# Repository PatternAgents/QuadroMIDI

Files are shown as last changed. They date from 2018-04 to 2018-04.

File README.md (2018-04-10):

# QuadroMIDI - Four channel MIDI Trigger I/O



Format : ERA / Eurorack / Breadboard Friendly

Height : 1U 

Width: 16HP

Depth : 1.0 cm

Power : +12V 40mA, -12V 40mA

Jacks : Thonkiconn Jacks (PJ301M-12)

The QuadroMIDI is a low cost, embeddable MIDI Trigger module

* Embedded Rack Architecture (Eurorack compatible)
* Optically Isolated MIDI Input Jack
* Driven MIDI Output Jack
* MIDI Clock Output Jack
* MIDI Run/Stop Output Jack
* Four (4) DC coupled  Trigger input channels
* Four (4) DC coupled  Trigger output channels
* Add an optional Front-Panel board for mounting in ERA and/or Eurorack enclosures

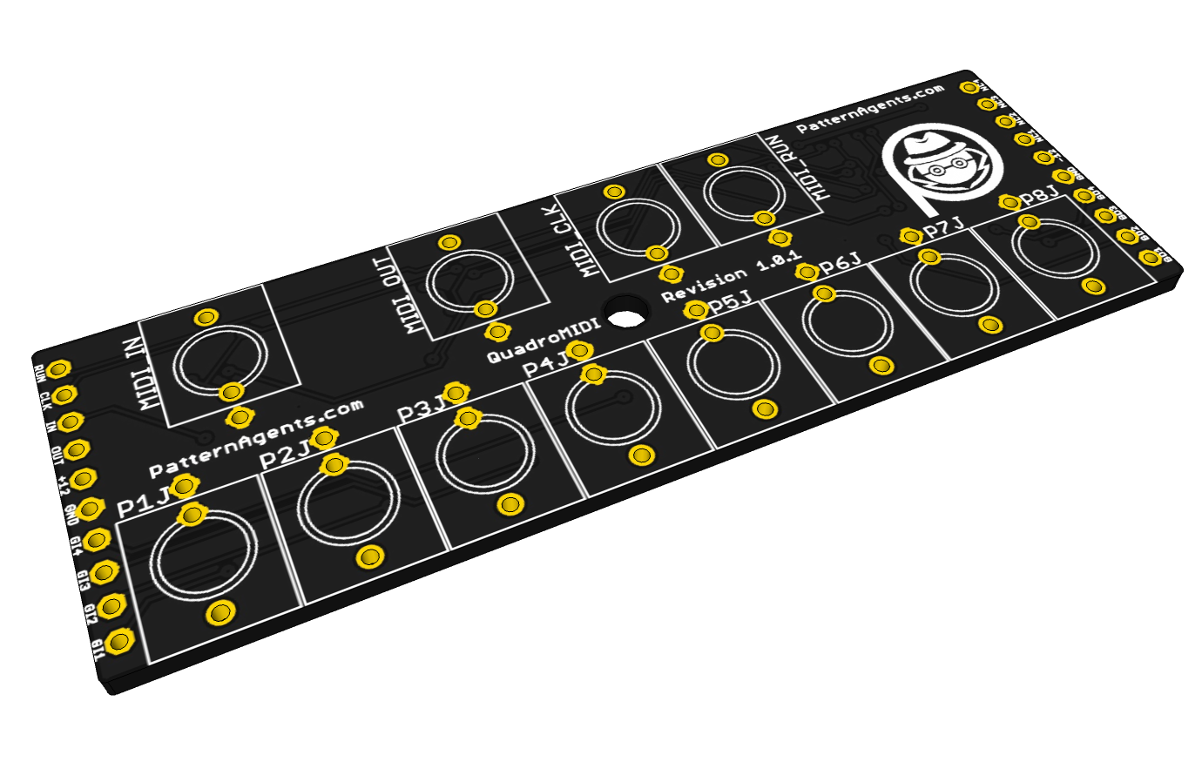
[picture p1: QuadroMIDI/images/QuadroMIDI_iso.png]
patternagents QuadroMIDI
[QuadroMIDI](https://github.com/patternagents/QuadroMIDI)

**thingSoC ERA** are OEM friendly implementations that implement various reference 
circuits for demonstrating the use of the PatternAgents IP and Libraries.

---------------------------------------
## QuadroMIDI Applications <a name="QuadroMIDI_Applications"/>

* MIDI to Trigger (Drum Piezo or other Human Interface)
* Add-on board for QuadroTeenia (MIDI I/O and Trigger I/O)

---------------------------------------
## QuadroMIDI Status <a name="QuadroMIDI_Status"/>

**4/10/2018:** 
Revision 1.0.0 - Initial Layout sent from OSHpark

---------------------------------------
## QuadroMIDI Model Images

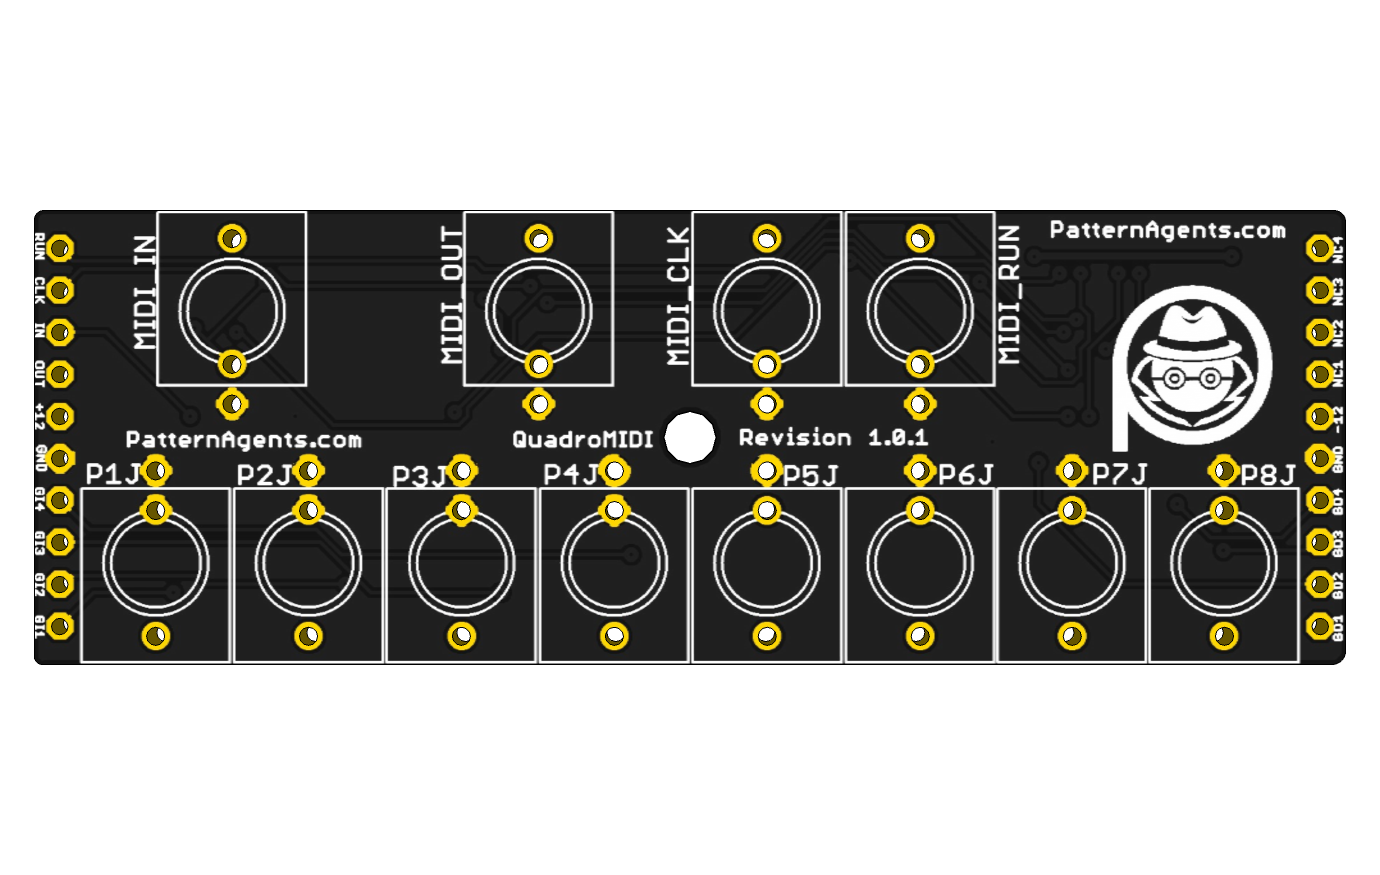
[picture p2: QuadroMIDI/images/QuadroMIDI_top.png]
patternagents QuadroMIDI
[QuadroMIDI](https://github.com/patternagents/QuadroMIDI)

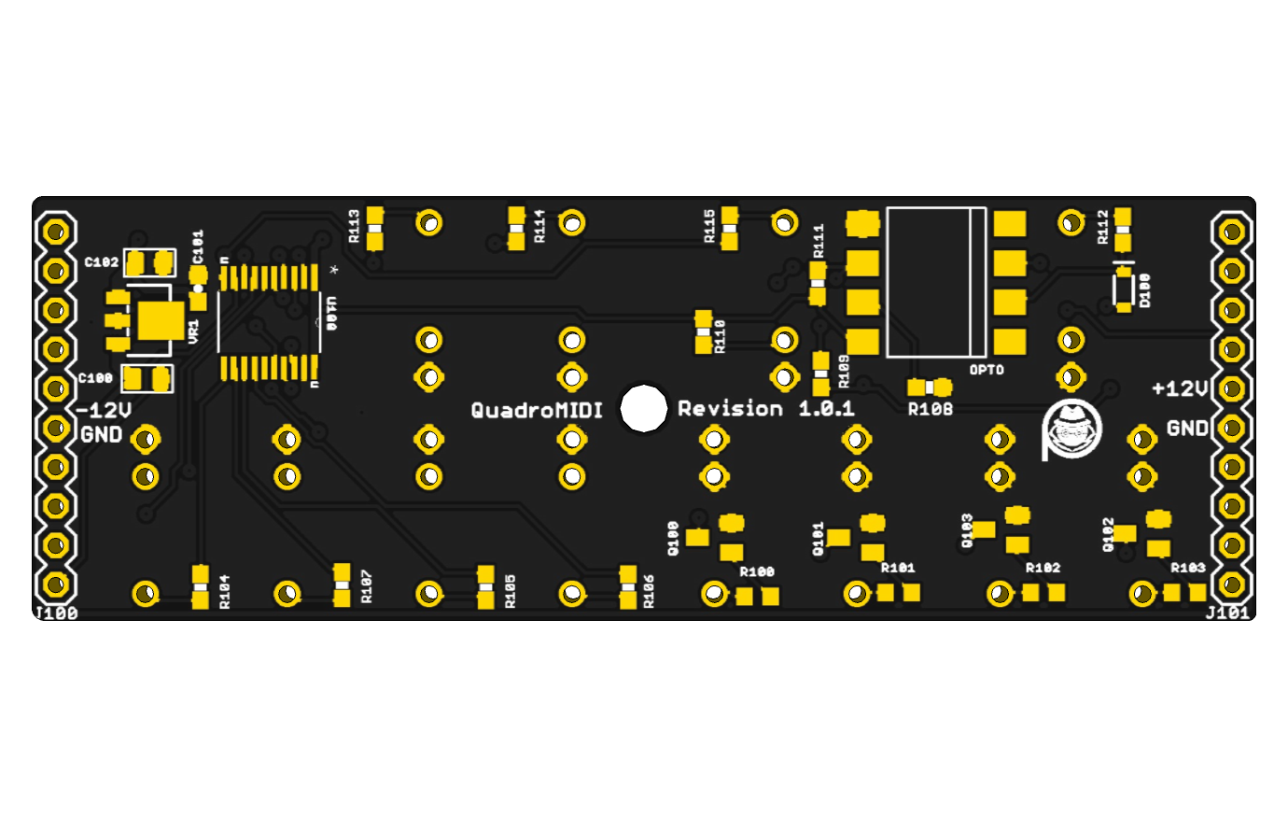
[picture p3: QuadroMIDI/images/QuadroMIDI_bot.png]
patternagents QuadroMIDI
[QuadroMIDI](https://github.com/patternagents/QuadroMIDI)

---------------------------------------

## QuadroMIDI Documentation Index <a name="QuadroMIDI_documentation_index"/>

[QuadroMIDI Project](http://thingsoc.github.io/projects/QuadroMIDI.html)

[QuadroMIDI Hardware](https://github.com/patternagents/QuadroMIDI/tree/master/QuadroMIDI/revisions/R1_0_0)

---------------------------------------

## Documentation Index <a name="documentation_index"/>

[Organization Website](http://patternagents.github.io)

[FAQ - Frequently Asked Questions](http://thingsoc.github.io/support/faq.html)

---------------------------------------

[thingSoC 
*PatternAgents, LLC*](http://thingsoc.github.io)

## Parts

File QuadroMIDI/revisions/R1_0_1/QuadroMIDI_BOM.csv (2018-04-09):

Qty | Value | Device | Package | Parts | Description
7 |  | RESISTOR0603-RES | 0603-RES | R104, R105, R106, R107, R113, R114, R115 | Resistor
1 | 0.1uF | CAP0603-CAP | 0603-CAP | C101 | Capacitor
1 | 0.5A/40V/420mV | DIODE-SCHOTTKY-PMEG4005EJ | SOD-323 | D100 | Schottky diode
4 | 100k | R-US_R0603 | R0603 | R100, R101, R102, R103 | RESISTOR, American symbol
3 | 1K | RESISTOR0603 | 0603-RES | R108, R109, R111 | Resistor
2 | 220 | RESISTOR0603 | 0603-RES | R110, R112 | Resistor
2 | 4.7uf | CERAMIC-4.7UF-25V-10%-X5R(0805) | C0805 | C100, C102 | 302010146
1 | 6N137SMT | 6N137SMT | DIL8-SMD | OPTO | MOTOROLA OPTO COUPLER
1 | 78L05 | 78LXX-SOT89 | SOT89 | VR1 | VOLTAGE REGULATOR
2 | F10 | M10SILK_FEMALE_PTH | 1X10_OCTO | J100, J101 | Header 10
10 | JACK-3_5MM-MONO-SW-MIN | JACK-3_5MM-MONO-SW-MIN | WQP_PJ301M-MIN | MIDI_CLK, MIDI_RUN, P1J, P2J, P3J, P4J, P5J, P6J, P7J, P8J | Jack, 3.5mm, RIght Angle, Though-Hole
2 | JACK-3_5MM-STEREO | JACK-3_5MM-STEREO | WQP_PJ301M-MIN | MIDI_IN, MIDI_OUT | Stereo 3.5mm Jack (TRS - Tip, Ring, Sleeve)
4 | MMBT3904 | MMBT3904LT1-NPN-SOT23-BEC | SOT23-BEC | Q100, Q101, Q102, Q103 | NPN Transistror
1 | PA_LOGO_SYMLARGE | PA_LOGO_SYMLARGE | PA_LOGO_AGENT_LRG_SYM | $$U$1 | PatternAgents Logo Symbol
1 | PA_LOGO_SYMSMALL | PA_LOGO_SYMSMALL | PA_LOGO_AGENT_SMALL_SYM | U$100 | PatternAgents Logo Symbol
1 | SN74HC245PW | SN74HC245PW | SOP65P640X120-20N | U100 | OCTAL BUS TRANSCEIVERS

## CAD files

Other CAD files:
QuadroMIDI/revisions/R1_0_1/eagleUp/QuadroMIDI.skp

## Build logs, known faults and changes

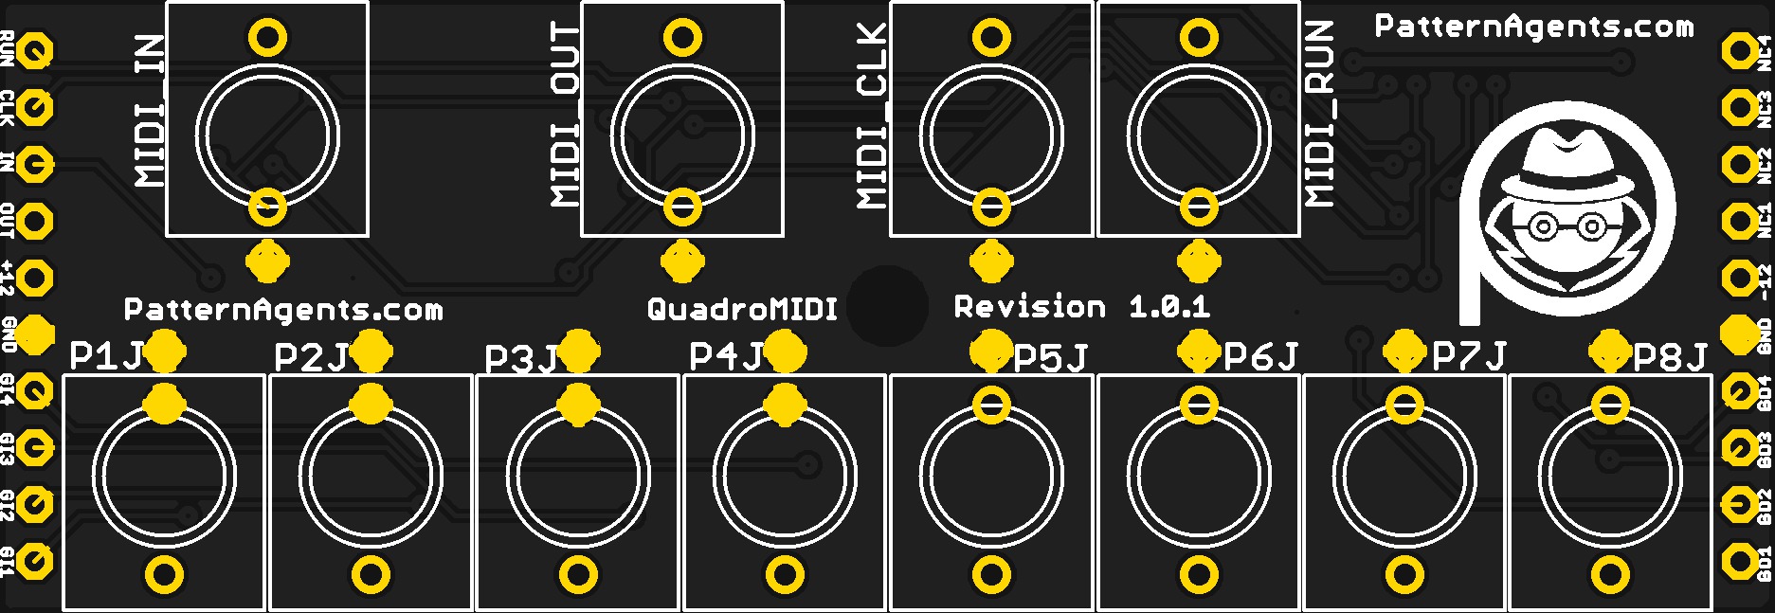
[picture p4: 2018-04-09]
QuadroMIDI/revisions/R1_0_1/eagleUp/eagleUp_QuadroMIDI_board_top.jpg

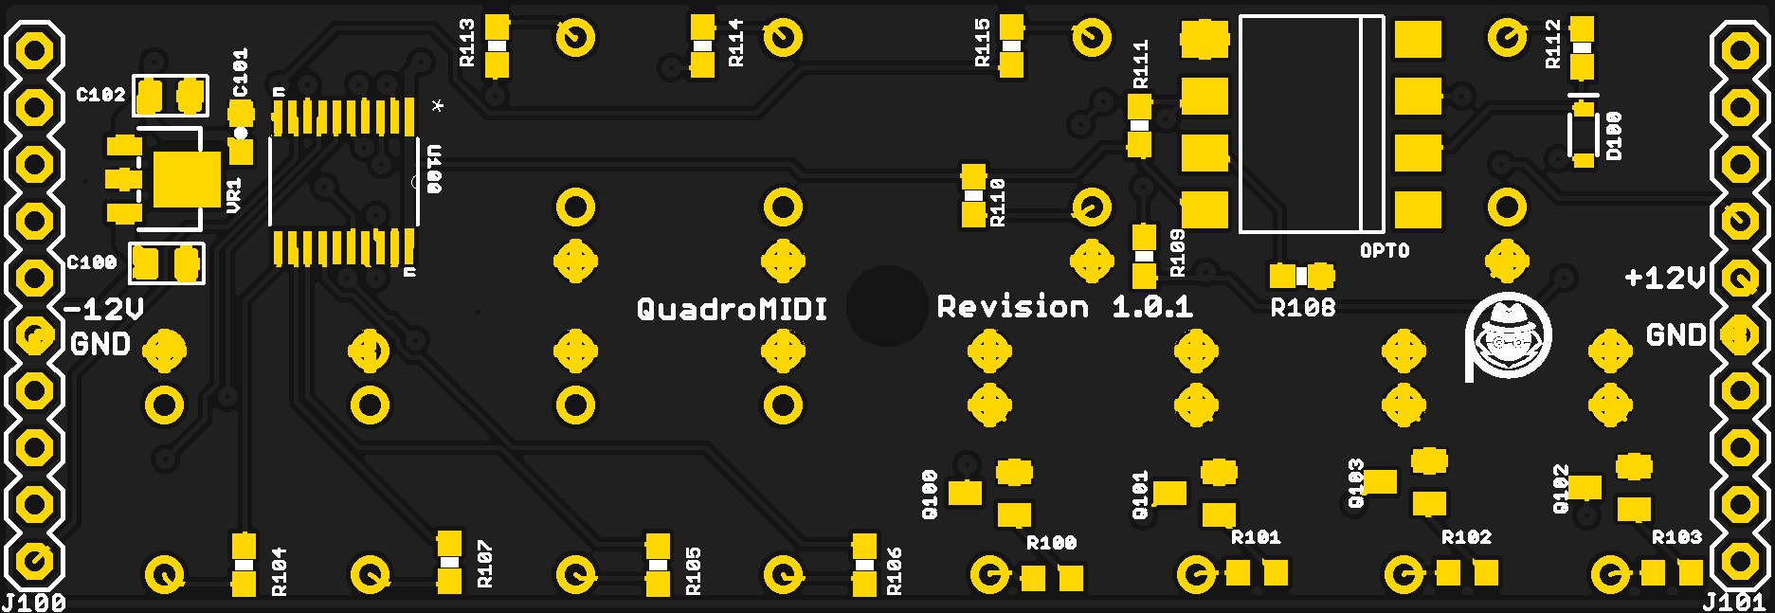
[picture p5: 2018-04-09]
QuadroMIDI/revisions/R1_0_1/eagleUp/eagleUp_QuadroMIDI_board_bottom.jpg

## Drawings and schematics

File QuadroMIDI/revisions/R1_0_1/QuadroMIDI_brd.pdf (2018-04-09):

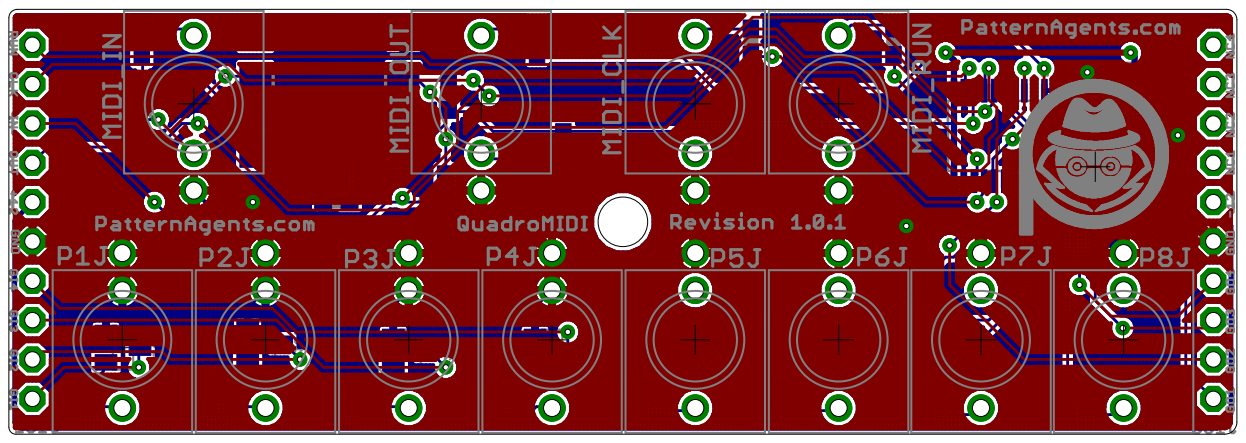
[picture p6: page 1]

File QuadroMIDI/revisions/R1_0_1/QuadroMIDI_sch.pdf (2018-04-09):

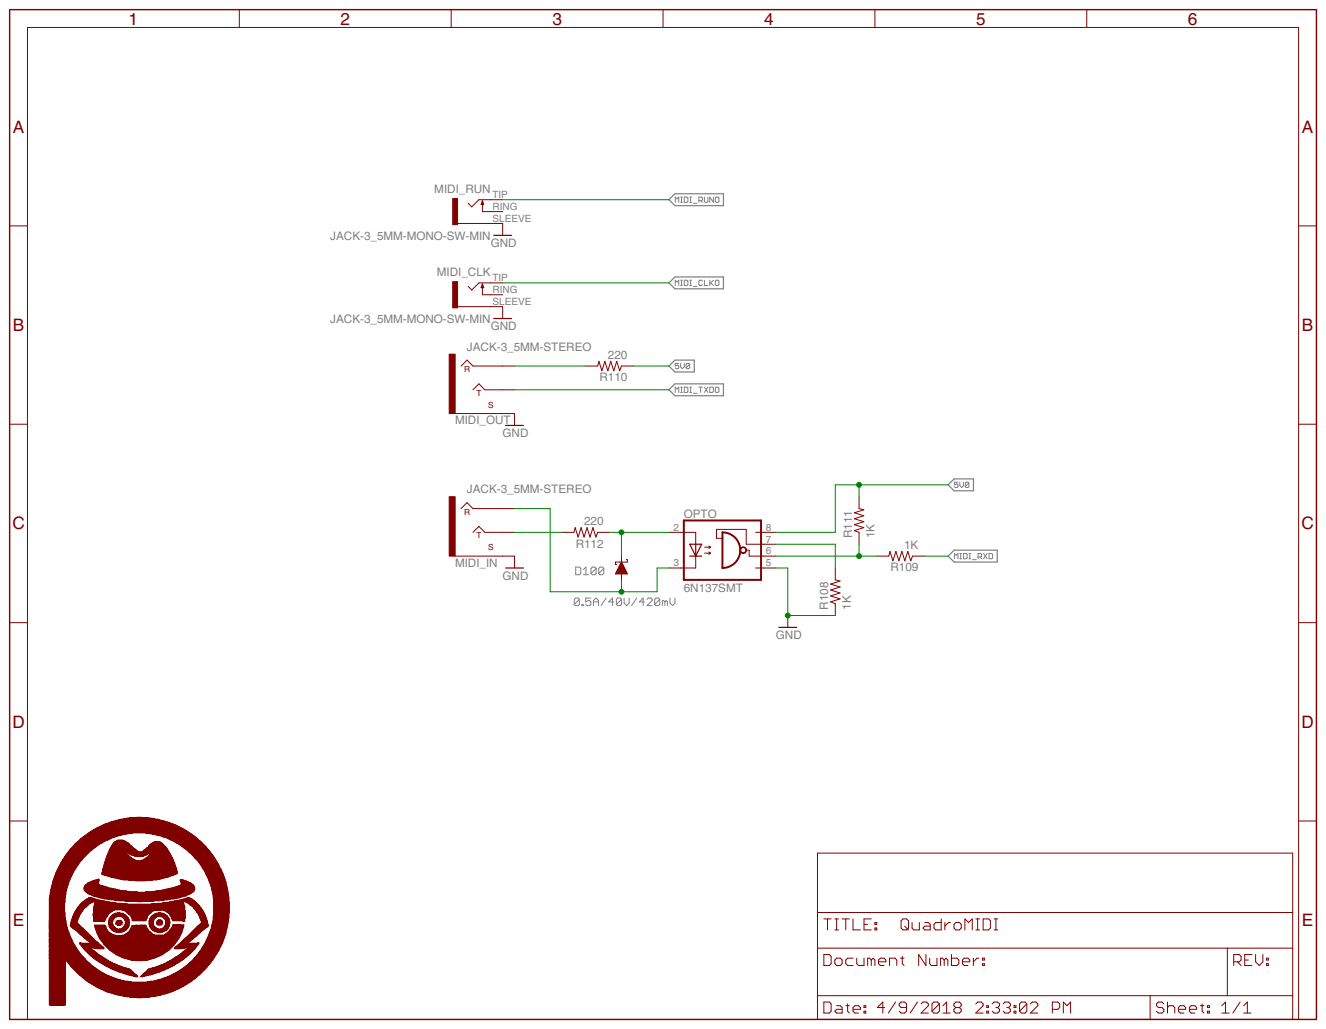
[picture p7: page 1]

JACK-3_5MM-MONO-SW-MIN

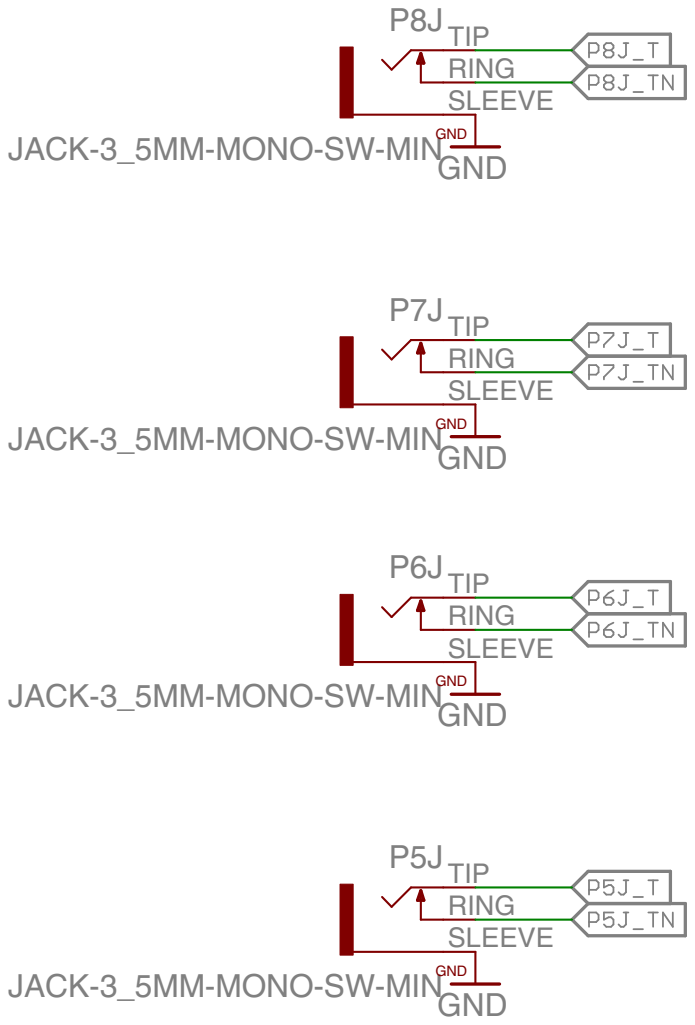
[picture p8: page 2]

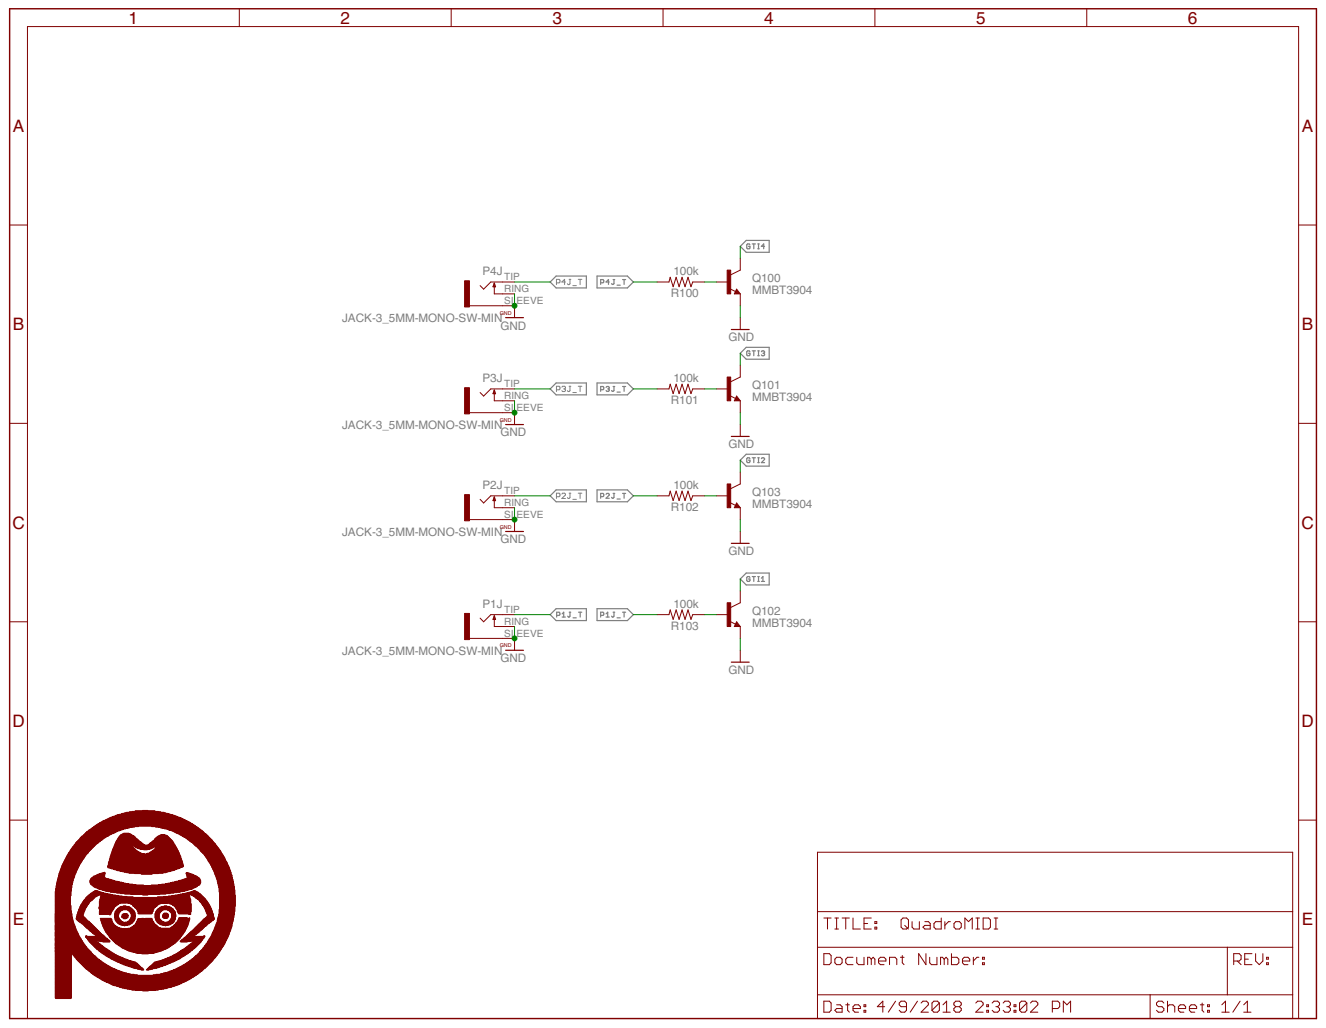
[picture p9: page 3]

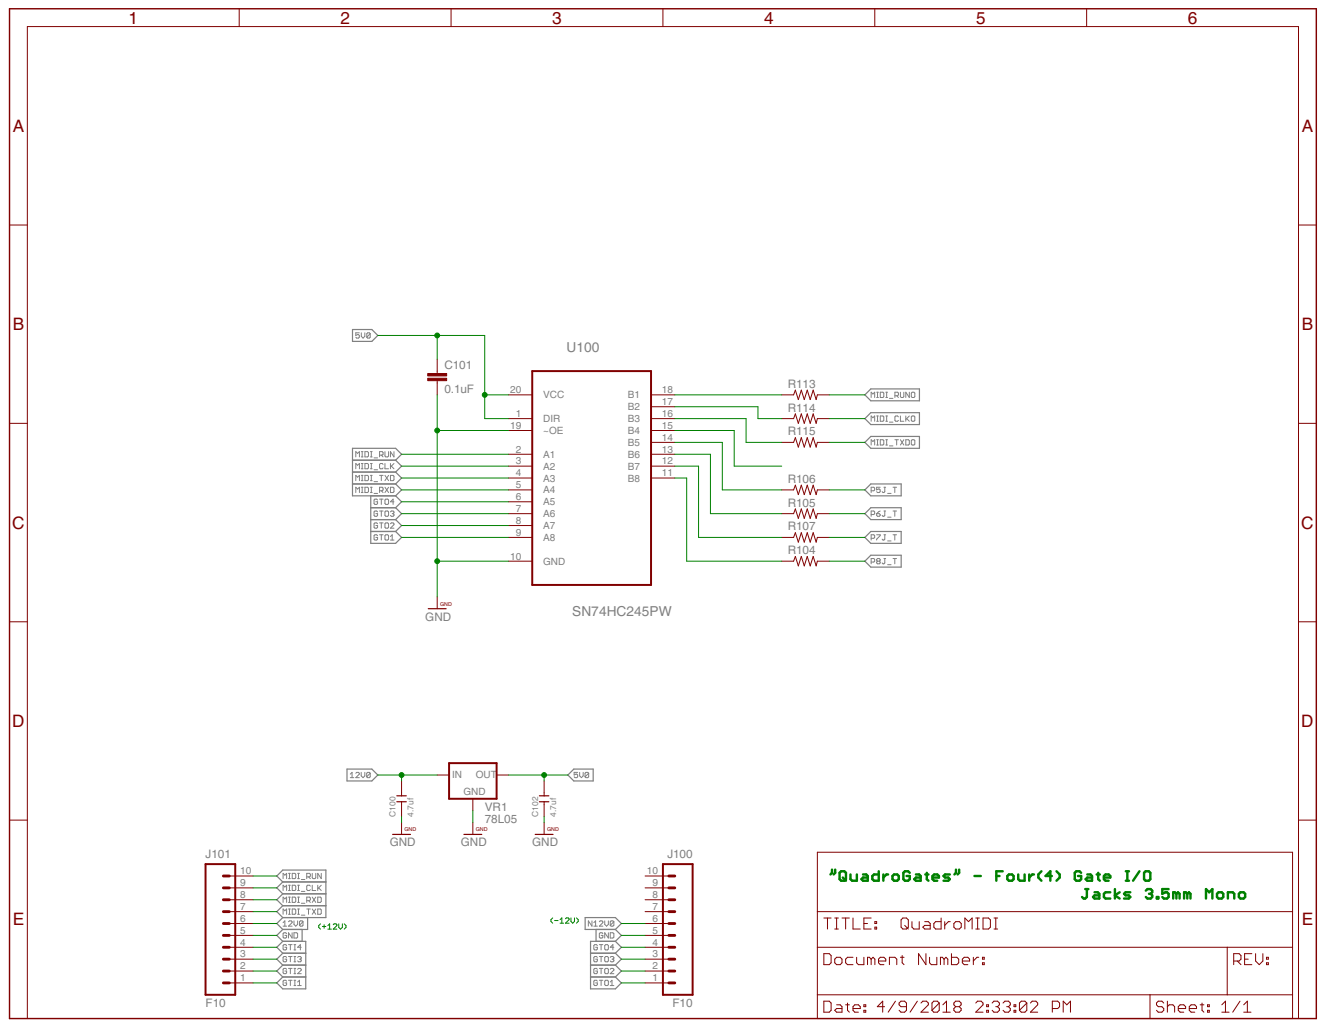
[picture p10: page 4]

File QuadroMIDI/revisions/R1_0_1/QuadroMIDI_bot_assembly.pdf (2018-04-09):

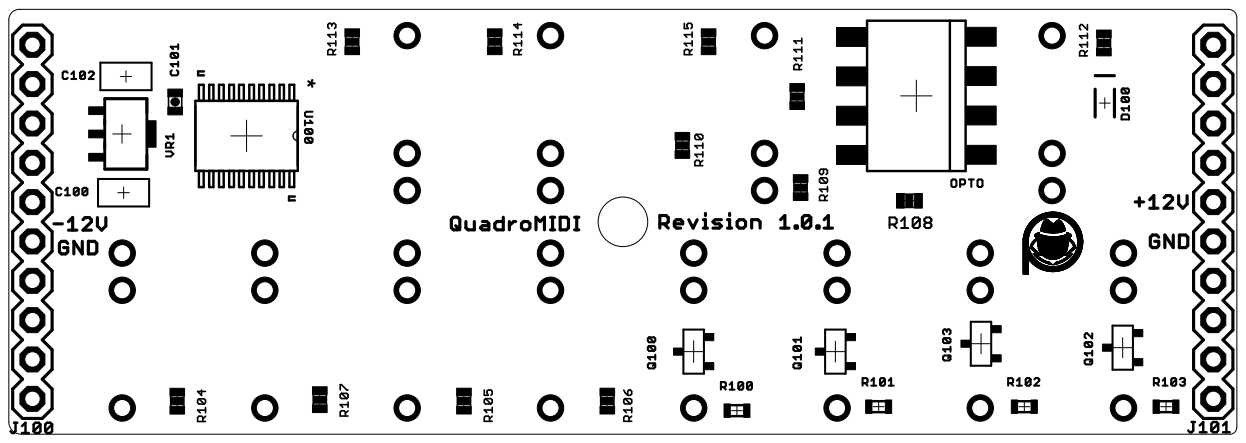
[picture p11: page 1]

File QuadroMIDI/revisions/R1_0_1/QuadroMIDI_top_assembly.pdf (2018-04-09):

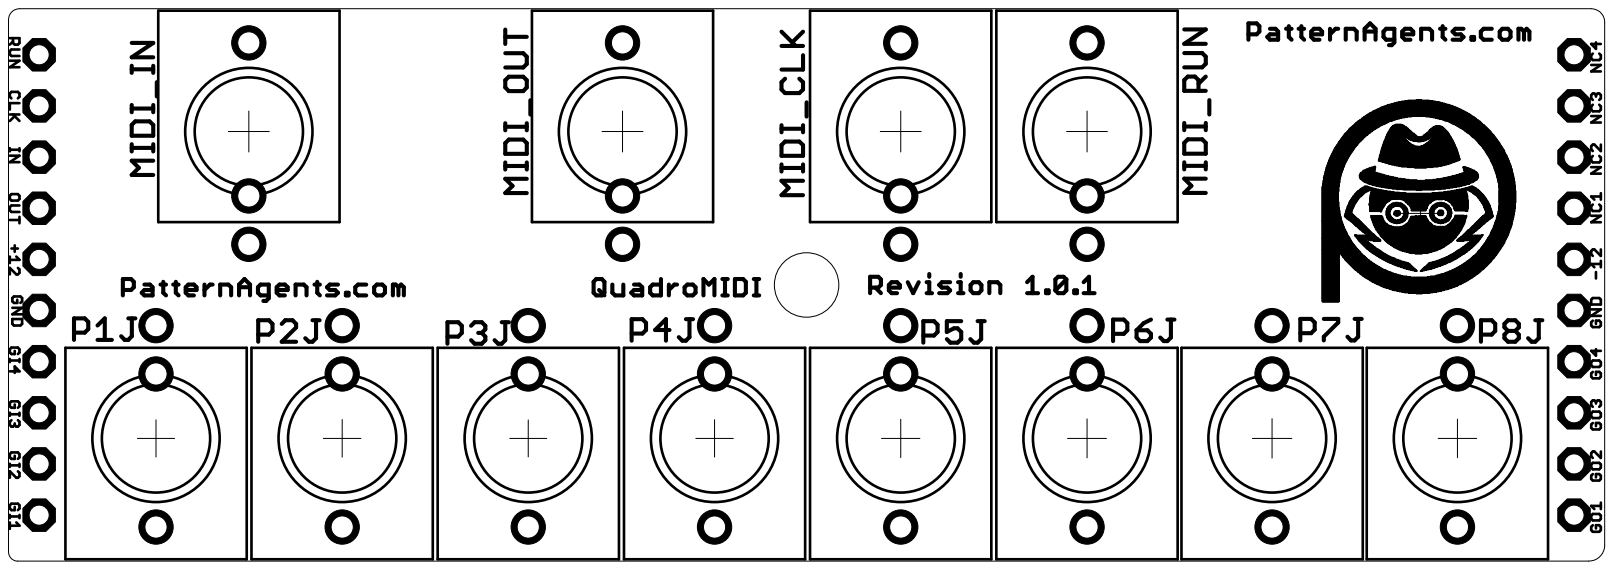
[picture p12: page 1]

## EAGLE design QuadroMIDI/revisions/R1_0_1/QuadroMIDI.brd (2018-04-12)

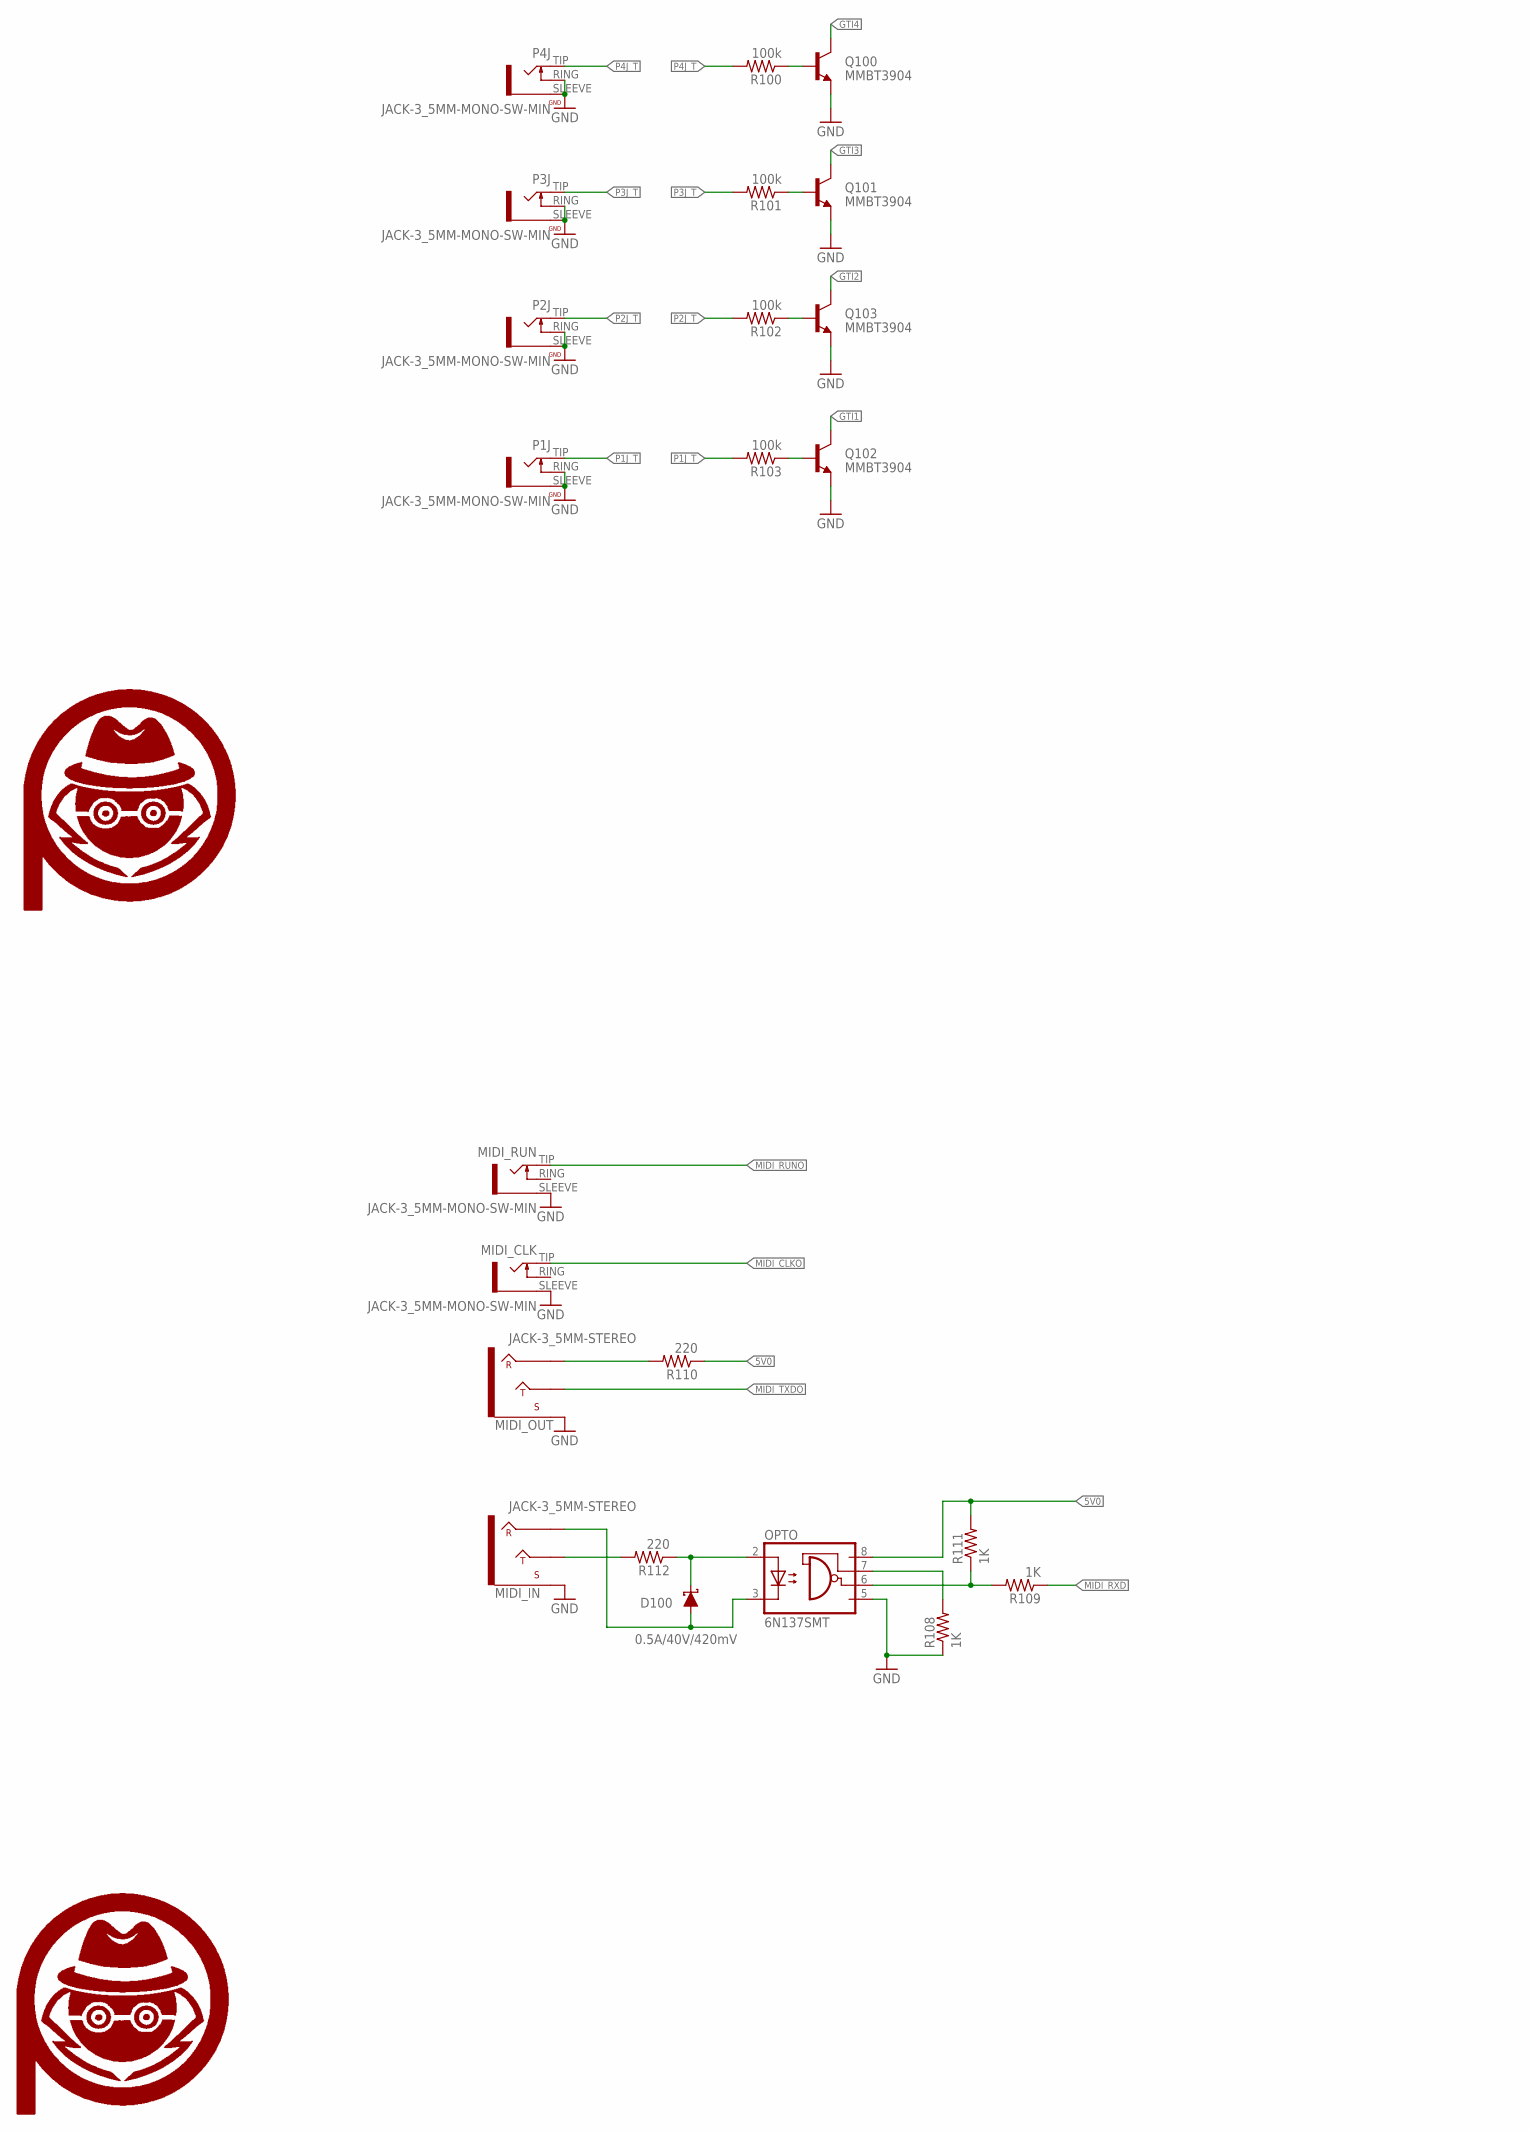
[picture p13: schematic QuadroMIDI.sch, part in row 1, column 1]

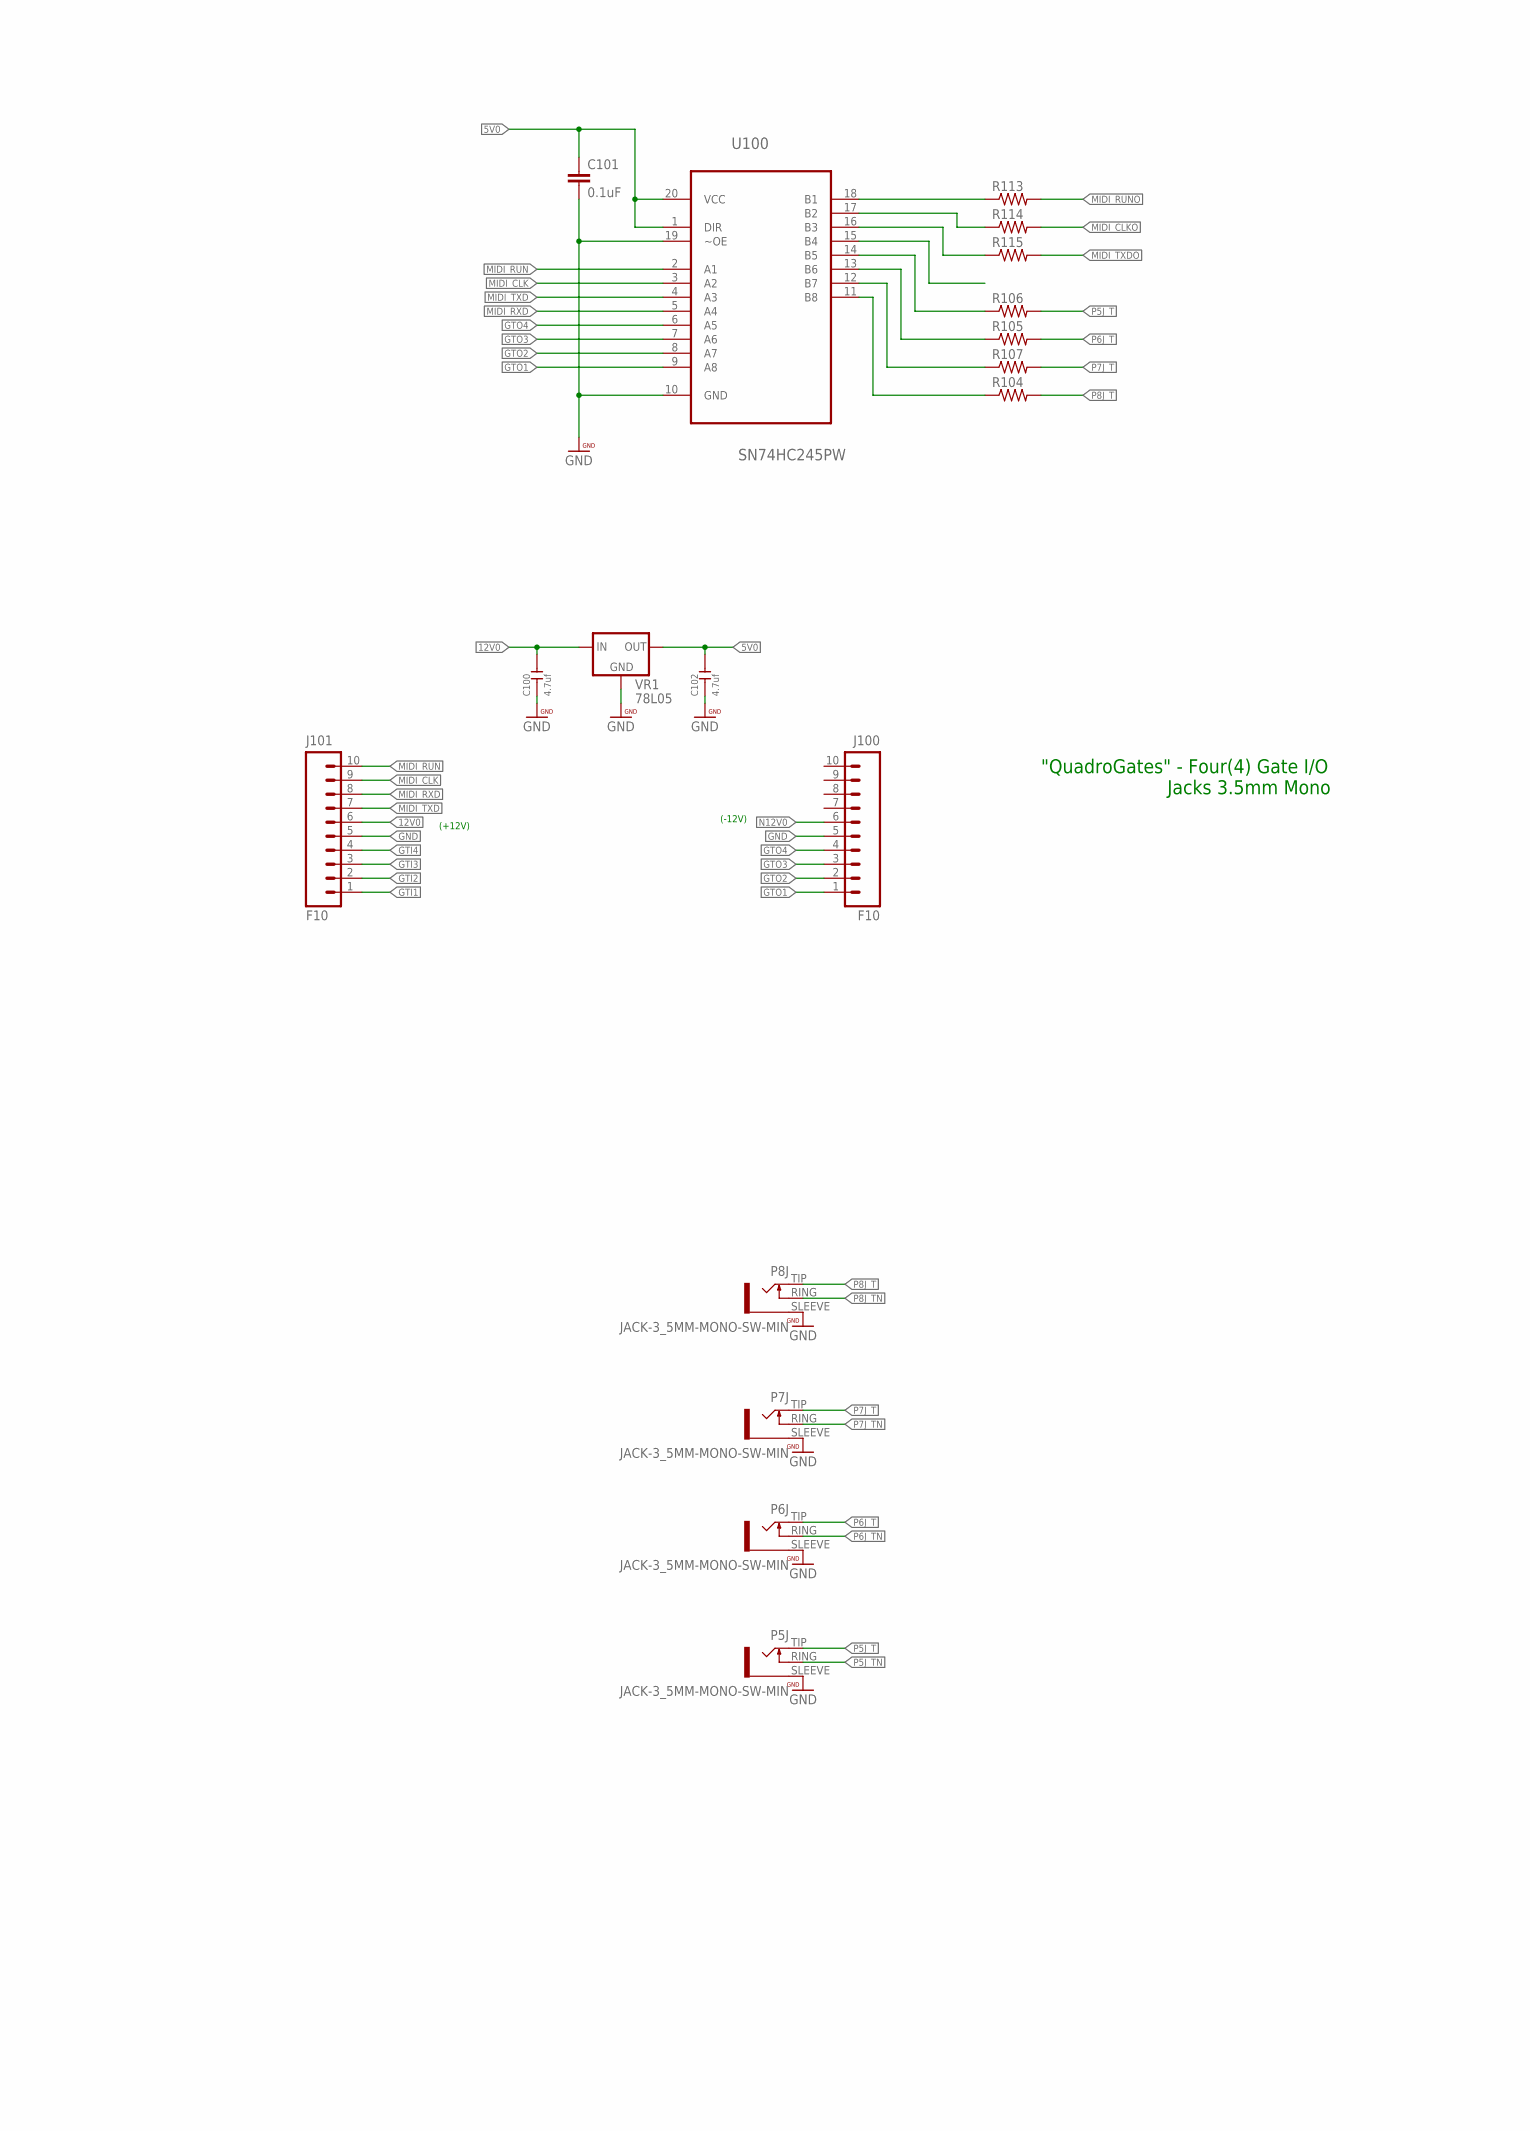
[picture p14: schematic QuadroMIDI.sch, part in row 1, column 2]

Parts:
$$U$1: PA_LOGO_SYMLARGE; PA_LOGO_AGENT_LRG_SYM
C100, C102: 4.7uf; C0805
C101: 0.1uF; 0603-CAP
D100: 0.5A/40V/420mV; SOD-323
J100, J101: F10; 1X10_OCTO
MIDI_CLK: JACK-3_5MM-MONO-SW-MIN; WQP_PJ301M-MIN
MIDI_IN: JACK-3_5MM-STEREO; WQP_PJ301M-MIN
MIDI_OUT: JACK-3_5MM-STEREO; WQP_PJ301M-MIN
MIDI_RUN: JACK-3_5MM-MONO-SW-MIN; WQP_PJ301M-MIN
OPTO: 6N137SMT; DIL8-SMD
P1J, P2J, P3J, P4J, P5J, P6J, P7J, P8J: JACK-3_5MM-MONO-SW-MIN; WQP_PJ301M-MIN
Q100, Q101, Q102, Q103: MMBT3904; SOT23-BEC
R100, R101, R102, R103: 100k; R0603
R104, R105, R106, R107, R113, R114, R115: RESISTOR0603-RES; 0603-RES
R108, R109, R111: 1K; 0603-RES
R110, R112: 220; 0603-RES
U100: SN74HC245PW; SOP65P640X120-20N
U$100: PA_LOGO_SYMSMALL; PA_LOGO_AGENT_SMALL_SYM
VR1: 78L05; SOT89

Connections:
5V0: C101.1, C102.2, OPTO.8 (VCC), R110.1, R111.2, U100.1 (DIR), U100.20 (VCC), VR1.1 (OUT)
12V0: C100.2, J101.6, VR1.3 (IN)
B1: R113.1, U100.18 (B1)
B2: R114.1, U100.17 (B2)
B3: R115.1, U100.16 (B3)
B4: U100.15 (B4)
B5: R106.1, U100.14 (B5)
B6: R105.1, U100.13 (B6)
B7: R107.1, U100.12 (B7)
B8: R104.1, U100.11 (B8)
GND: C100.1, C101.2, C102.1, J100.5, J101.5, MIDI_CLK.SLEEVE, MIDI_IN.SLEEVE, MIDI_OUT.SLEEVE, MIDI_RUN.SLEEVE, OPTO.5 (GND), P1J.RING (TIP_SW), P1J.SLEEVE, P2J.RING (TIP_SW), P2J.SLEEVE, P3J.RING (TIP_SW), P3J.SLEEVE, P4J.RING (TIP_SW), P4J.SLEEVE, P5J.SLEEVE, P6J.SLEEVE, P7J.SLEEVE, P8J.SLEEVE, Q100.E, Q101.E, Q102.E, Q103.E, R108.1, U100.10 (GND), U100.19 (~OE), VR1.2 (GND)
GTI1: J101.1, Q102.C
GTI2: J101.2, Q103.C
GTI3: J101.3, Q101.C
GTI4: J101.4, Q100.C
GTO1: J100.1, U100.9 (A8)
GTO2: J100.2, U100.8 (A7)
GTO3: J100.3, U100.7 (A6)
GTO4: J100.4, U100.6 (A5)
MIDIP: MIDI_IN.TIP, R112.2
MIDIRX: OPTO.6 (VO), R109.2, R111.1
MIDI_CLK: J101.9, U100.3 (A2)
MIDI_CLKO: MIDI_CLK.TIP, R114.2
MIDI_RUN: J101.10, U100.2 (A1)
MIDI_RUNO: MIDI_RUN.TIP, R113.2
MIDI_RXD: J101.8, R109.1, U100.5 (A4)
MIDI_TXD: J101.7, U100.4 (A3)
MIDI_TXDO: MIDI_OUT.TIP, R115.2
MIDN: D100.A, MIDI_IN.RING, OPTO.3 (C)
MIDP: D100.C, OPTO.2 (A), R112.1
N12V0: J100.6
unnamed: Q102.B, R103.1
unnamed: Q103.B, R102.1
unnamed: MIDI_OUT.RING, R110.2
unnamed: Q101.B, R101.1
unnamed: Q100.B, R100.1
OPTO: OPTO.7 (VE), R108.2
P1J_T: P1J.TIP, R103.2
P2J_T: P2J.TIP, R102.2
P3J_T: P3J.TIP, R101.2
P4J_T: P4J.TIP, R100.2
P5J_T: P5J.TIP, R106.2
P5J_TN: P5J.RING (TIP_SW)
P6J_T: P6J.TIP, R105.2
P6J_TN: P6J.RING (TIP_SW)
P7J_T: P7J.TIP, R107.2
P7J_TN: P7J.RING (TIP_SW)
P8J_T: P8J.TIP, R104.2
P8J_TN: P8J.RING (TIP_SW)

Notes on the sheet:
(+12V)
(-12V)
"QuadroGates" - Four(4) Gate I/O Jacks 3.5mm Mono

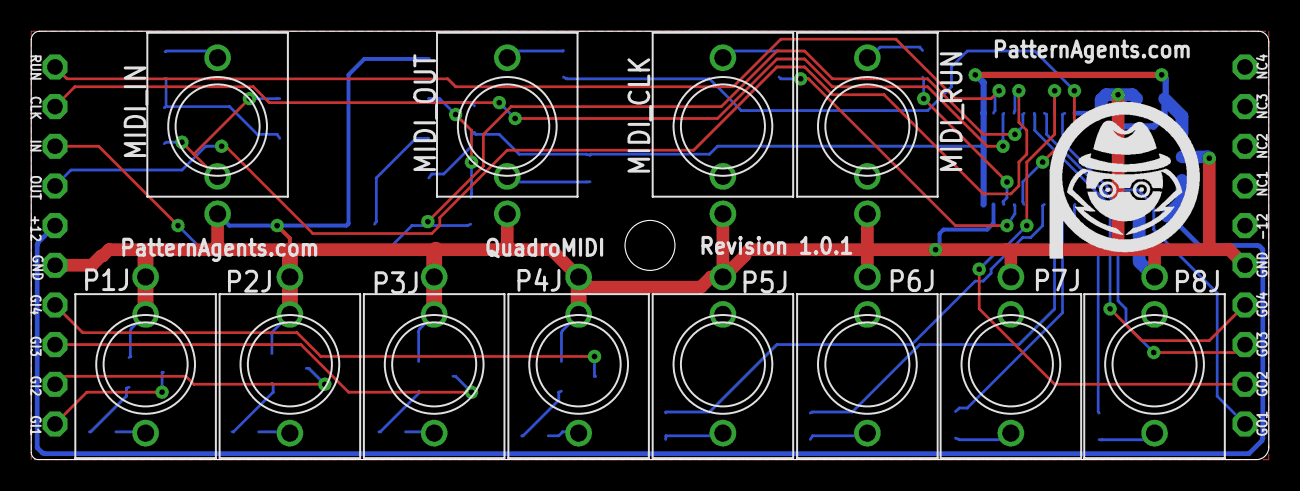
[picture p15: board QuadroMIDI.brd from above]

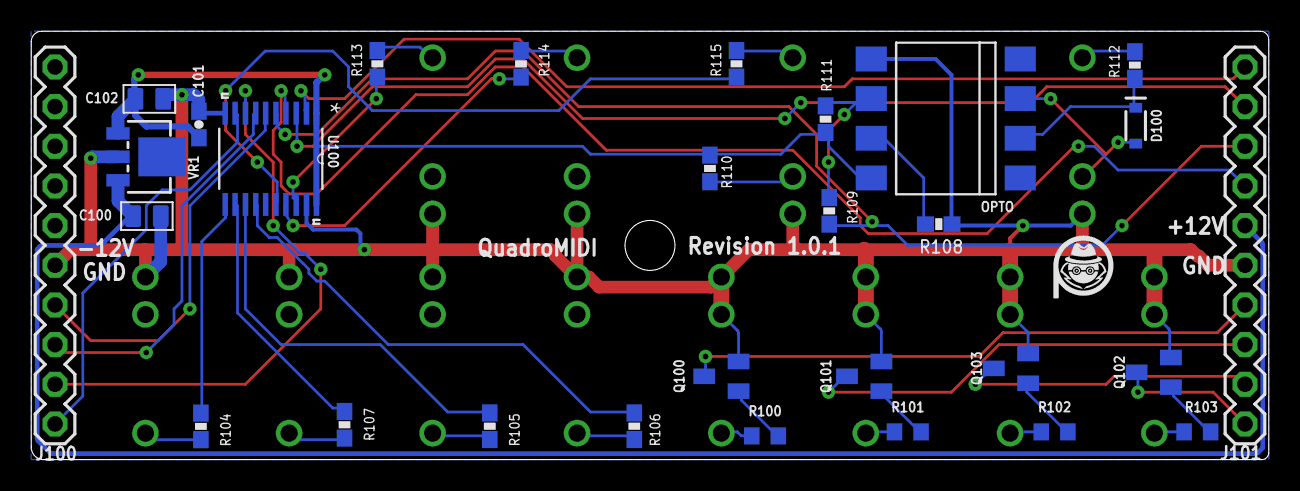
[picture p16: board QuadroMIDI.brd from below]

Board: 2 copper layers, 79.2 x 27.4 mm, 43 parts (30 on the bottom side), 43 nets.

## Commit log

2018-04-09 initial version
    [QuadroMIDI.brd, QuadroMIDI.sch, QuadroMIDI.skp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]
2018-04-12 First Release
    [QuadroMIDI.brd]

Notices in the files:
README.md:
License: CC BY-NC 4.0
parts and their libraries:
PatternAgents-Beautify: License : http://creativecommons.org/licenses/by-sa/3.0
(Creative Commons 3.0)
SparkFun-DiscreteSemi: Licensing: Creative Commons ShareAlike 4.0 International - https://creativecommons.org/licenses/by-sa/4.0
